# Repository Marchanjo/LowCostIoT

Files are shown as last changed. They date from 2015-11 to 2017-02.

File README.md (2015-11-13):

# LowCostIoT
Hardware, Embedded software and Android App for Internet of Things, with low cost components.

Mapa do projeto
---------------
* **/TOM2015/Firmware** - Firmware e Código ESP8266 (Tomada e Interrptor)
* **/TOM2015/Hardware** - Arquivos de design (Eagle) da PCB, esquemáticos e gerbers (Tomada e Interrptor)
* **/TOM2015/App** - Código da aplicação Android
* **/TOM2015/Bin** - Arquivos binários (APK)

Licença
-------
O hardware e o software estão disponiveis em [Creative Commons Atribuição-NãoComercial-CompartilhaIgual 4.0 Internacional. License.](http://creativecommons.org/licenses/by-nc-sa/4.0/)
 
The hardware and the software are released under [Creative Commons Atribuição-NãoComercial-CompartilhaIgual 4.0 Internacional. License.](http://creativecommons.org/licenses/by-nc-sa/4.0/)

Distribuido como está, nenhuma garantia é dada.

Distributed as-is; no warranty is given.

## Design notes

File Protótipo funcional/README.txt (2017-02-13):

ESP8266
- com NodeMCU : flash feito pelo ESPtool (arquivo nodemcu na pasta esptool) 
	- conexão dos esp com cabo FTDI: http://cdn.instructables.com/FLB/M8JA/I3VHABJ2/FLBM8JAI3VHABJ2.MEDIUM.jpg
		em alguns casos deve-se colocar o RESET em alto
	- para fazer o flash: python esptool.py --port COMX write_flash 0x00000 arquivo_que_tem_o_firmware.bin
- enviar o init.lua para o esp por meio do ESPlorer, escolher a porta e o baudrate (normamente é 9600 ou 115200)
	- mudar ip que é setado na programação (192.168.0.95) se necessário 
	- se não funcionar testar subir o arquivo "teste_site.lua" e abrir em um browser o "ip"+":80" (para descobrir o ip envie "wifi.sta.getip()" por serial no ESPlorer)

Aplicativo
- simples para envio de comandos "on" ou "off" para o ESP.
- selecionar ip e porta
- somente HomeActivity está sendo utilizado.

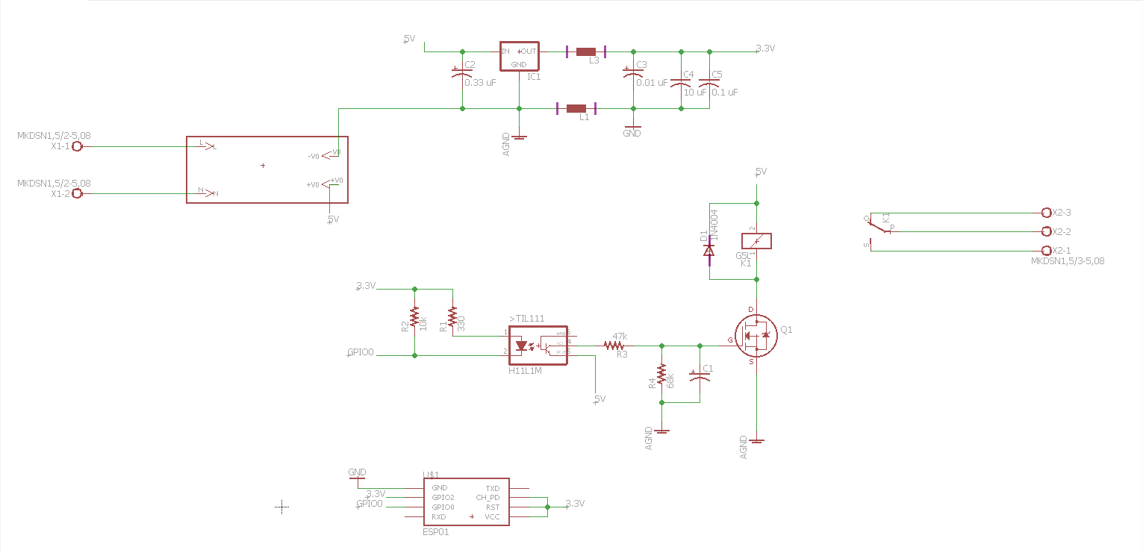
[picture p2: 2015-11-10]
TOM2015/Hardware/Interruptor/Interruptor.png

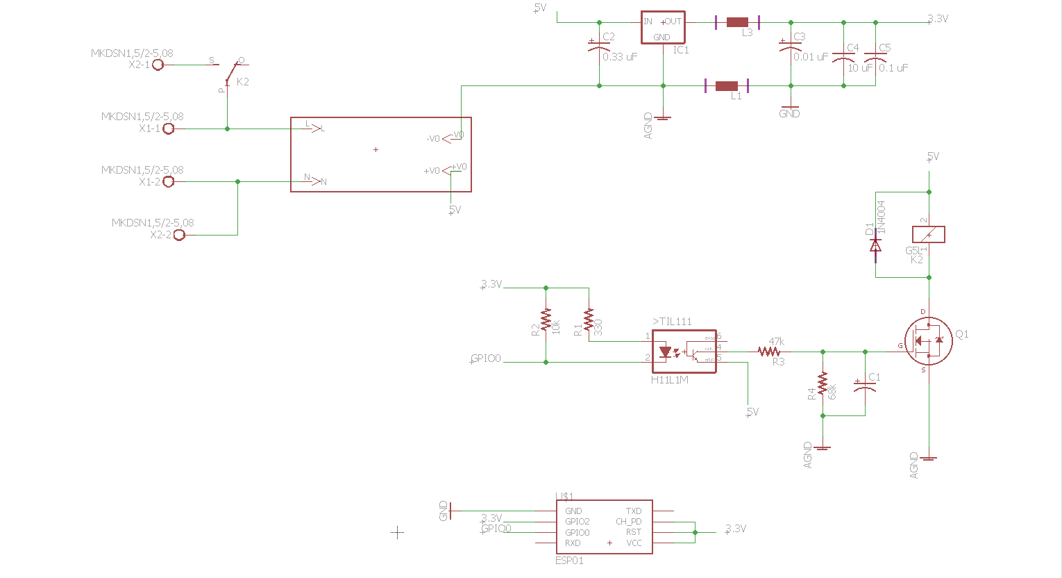
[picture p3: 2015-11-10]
TOM2015/Hardware/Tomada/tomada.png

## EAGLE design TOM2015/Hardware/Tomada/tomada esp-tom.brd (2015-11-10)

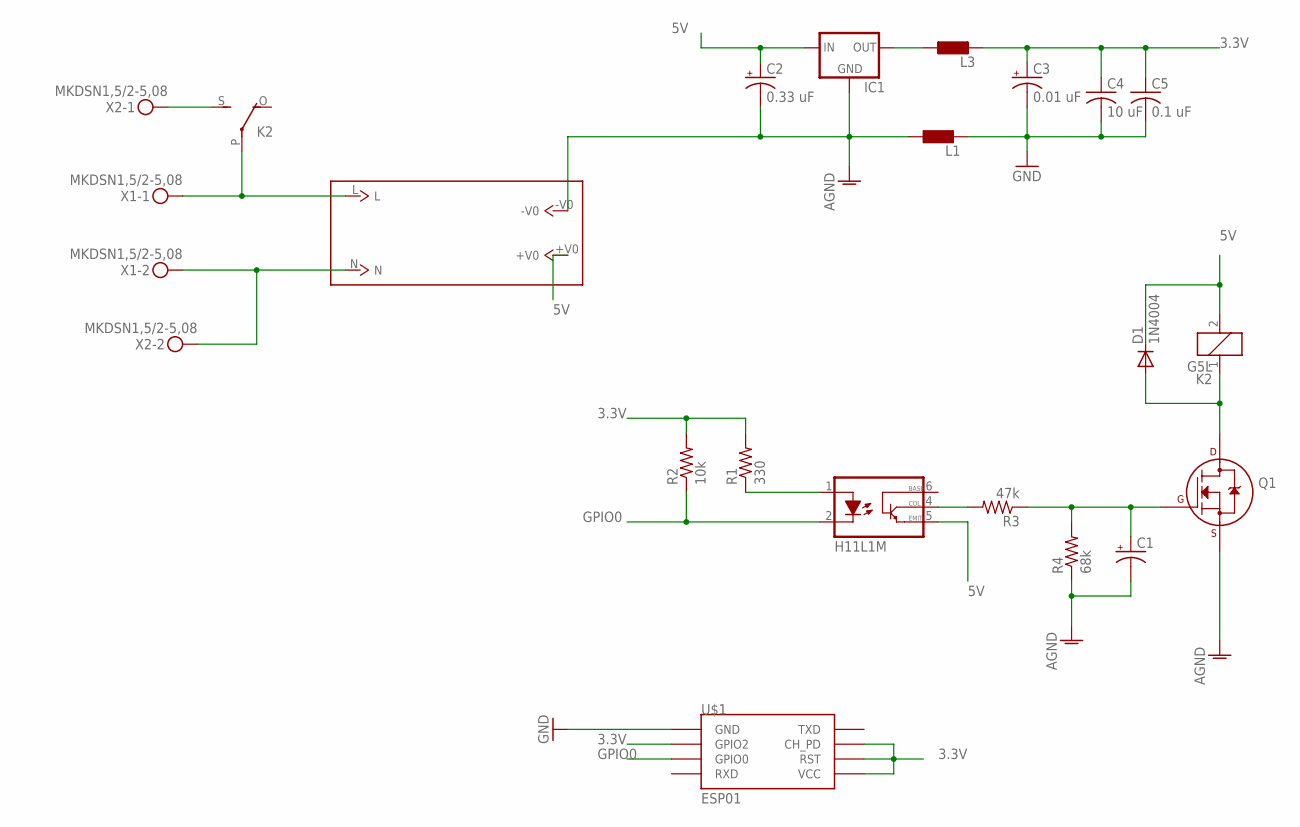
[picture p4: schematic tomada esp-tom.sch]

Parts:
C1: CPOL-USE2-5; E2-5
C2: 0.33 uF; E2-5
C3: 0.01 uF; E2-5
C4: 10 uF; C025-024X044
C5: 0.1 uF; C025-024X044
D1: 1N4004; DO41-10
IC1: 78LXX
K2: G5L; G5LE
L1, L3: L0207/10; 0207/10
OK1: H11L1M; DIL06
Q1: 2N7000_TO92; TO-92
R1: 330; 0204/7
R2: 10k; 0204/7
R3: 47k; 0204/7
R4: 68k; 0204/7
U$1: ESP01
U$2: NA03-T2S05
X1, X2: MKDSN1,5/2-5,08

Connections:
3.3V: C3.+, C4.1, C5.1, L3.2, R1.2, R2.2, U$1.CH_PD, U$1.GPIO2, U$1.RST, U$1.VCC
5V: C2.+, D1.C, IC1.IN, K2.2, OK1.5 (GND), U$2.+V0
AGND: C1.-, C2.-, IC1.GND, L1.1, Q1.1 (S), R4.1, U$2.-V0
GND: C3.-, C4.2, C5.2, L1.2, U$1.GND
GPIO0: OK1.2 (C), R2.1, U$1.GPIO0
unnamed: OK1.1 (A), R1.1
unnamed: C1.+, Q1.2 (G), R3.1, R4.2
unnamed: OK1.4 (OUT), R3.2
unnamed: D1.A, K2.1, Q1.3 (D)
unnamed: K2.S, X2.1
unnamed: K2.P, U$2.L, X1.1
unnamed: U$2.N, X1.2, X2.2
unnamed: IC1.OUT, L3.1
VCC: OK1.6 (VCC)

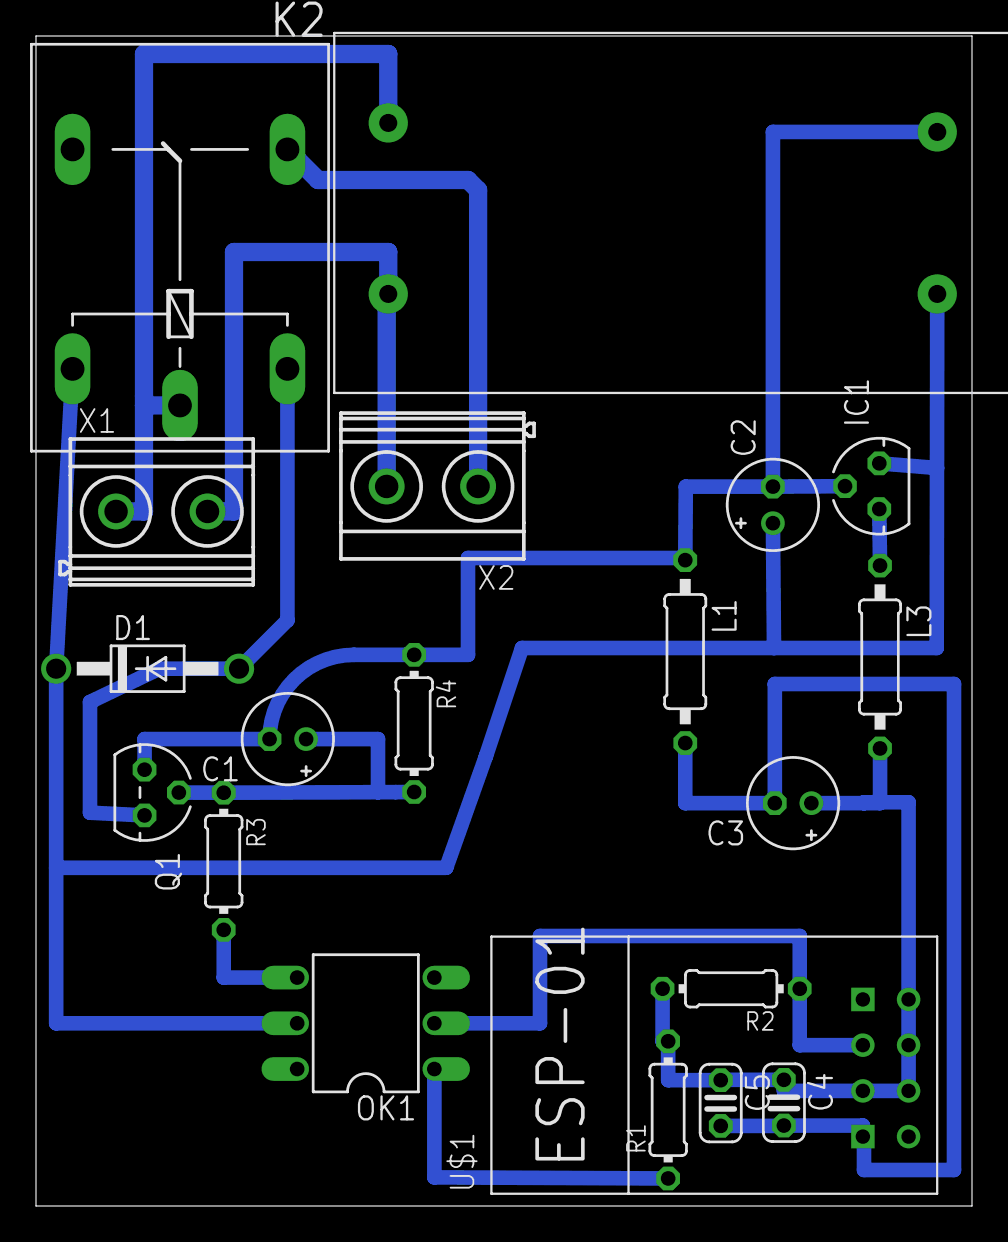
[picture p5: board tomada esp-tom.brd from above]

Board: 2 copper layers, 52.0 x 65.0 mm, 20 parts (0 on the bottom side), 13 nets.

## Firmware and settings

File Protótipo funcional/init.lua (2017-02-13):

nome = "interruptor"
rele = 3
gpio.mode(rele, gpio.OUTPUT)
gpio.write(rele, gpio.HIGH)
status = "desligado"
wifi.setmode(wifi.STATION)
wifi.sta.config("CITI-Terreo","1cbe991a14")
wifi.sta.setip({ip="192.168.0.95", netmask="255.255.255.0", gateway="192.168.0.1"})
wifi.sta.autoconnect(1)
if server then
    server:close()
end
server=net.createServer(net.TCP)
server:listen(80, function(conexao)
    conexao:on("receive", function(cliente, mensagem)
        if mensagem then
            print(mensagem)
            ini1, ini2 = mensagem:find("GET")
            fim1, fim2 = mensagem:find("HTTP")
            dado = mensagem:sub(ini2+3, fim1-2)
            print(dado)   
            if dado == "?pin=on" then
                gpio.write(rele, gpio.LOW)
                status = "ligado"    
            end      
            if dado == "?pin=off" then
                gpio.write(rele, gpio.HIGH)
                status = "desligado"
            end
            resposta = nome .. "_" .. status
            tamanho = string.len(resposta)
            reply = "HTTP/1.1 200 OK\r\nContent-Length:" .. tostring(tamanho) .. "\r\nConnection:close\r\n\r\n"..resposta
            conexao:send(reply)
            --tamanho = string.len(resposta)
            --conexao:send("HTTP/1.1 200 OK")
            --conexao:send("Content-Length:" .. tostring(tamanho))
            --conexao:send("Connection:close\r\n")
            --conexao:send(resposta)
        end
    end)
    conexao:on("sent", function(conexao) conexao:close() end)
end)

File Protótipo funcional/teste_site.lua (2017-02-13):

-- Programa: Web Server com ESP8266 Nodemcu
-- Autor: FILIPEFLOP
 
-- Conexao na rede Wifi
wifi.setmode(wifi.STATION)
wifi.sta.config("CITI-Terreo","1cbe991a14")
print(wifi.sta.getip())
-- Definicoes do pino do led
led1 = 1
gpio.mode(led1, gpio.OUTPUT)
-- Definicoes do Web Server
srv=net.createServer(net.TCP)
srv:listen(80,function(conn)
    conn:on("receive", function(client,request)
        local buf = "";
        local _, _, method, path, vars = string.find(request, "([A-Z]+) (.+)?(.+) HTTP");
        if(method == nil)then
            _, _, method, path = string.find(request, "([A-Z]+) (.+) HTTP");
        end
        local _GET = {}
        if (vars ~= nil)then
            for k, v in string.gmatch(vars, "(%w+)=(%w+)&*") do
                _GET[k] = v
            end
        end
        buf = buf.."<h1><u>FILIPEFLOP</u></h1>";
        buf = buf.."<h2><i>ESP8266 Web Server</i></h2>";
        buf = buf.."<p><a href=\"?pin=LIGA1\"><button><b>LED 1 LIG</b></button></a> <br/><br/><a href=\"?pin=DESLIGA1\"><button><b>LED 1 DES</b></button></a></p>";
                local _on,_off = "",""
        if(_GET.pin == "LIGA1")then
              gpio.write(led1, gpio.HIGH);
        elseif(_GET.pin == "DESLIGA1")then
              gpio.write(led1, gpio.LOW);
        end
        client:send(buf);
        client:close();
        collectgarbage();
    end)
end)

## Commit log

2015-11-09 Organização da Estrutura de diretórios
    Criada uma estrutura na raíz para tudo que foi apresentado no TOM 2015.
    [esp-tom.brd, esp-tom.sch, tomada esp-tom.brd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]
2015-11-10 Versão final do tom
    Versão final do Tom com as ligações do esp corretas e o desenho correto
    do componente TIL111
    [esp-tom.brd, esp-tom.sch, tomada esp-tom.brd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]
2015-11-10 Adicionadas as imagens do esquemático
    Adicionadas as imagens do esquemático tanto do interruptor, quanto da
    tomada
2015-11-26 mais informações para reutilização do código
